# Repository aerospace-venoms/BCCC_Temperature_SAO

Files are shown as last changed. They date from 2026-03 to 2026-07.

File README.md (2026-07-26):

# BCCC SAO Temperature Badge

A Simple Add-On (SAO) badge for the DEF CON Beverage Chilling Contraption Contest (BCCC). Winners of the contest receive copies of this badge, at least for this year (2026) or until I run out.

The PCB is shaped like a red solo cup with overflowing beer. It reads ambient temperature using a DS18B20 sensor and displays the result in degrees Fahrenheit on three 7-segment LED displays.

## Hardware

- **MCU:** Raspberry Pi RP2350A (QFN-60)
- **Flash:** W25Q16 (2 MB)
- **Sensor:** DS18B20 1-Wire temperature sensor (GPIO 16); falls back to the RP2350's internal die sensor if not present
- **Display:** 3x common-anode 7-segment LED displays, multiplexed via a 74HC595 shift register
- **Interface:** USB-C (programming and serial debug output)
- **Extras:** 3-pin SWD debug header, user pushbuttons (RUN, QSPI_SS/BOOTSEL, and a brightness button on GPIO 19)

### Pin Assignments

| Signal | GPIO |
|---|---|
| 1-Wire (DS18B20) | 16 |
| Digit select 1 (leftmost) | 8 |
| Digit select 2 (middle) | 9 |
| Digit select 3 (rightmost) | 10 |
| 74HC595 SER (data) | 11 |
| 74HC595 SRCLK (shift clock) | 12 |
| 74HC595 RCLK (latch clock) | 13 |
| 74HC595 /OE (output enable) | 14 |
| 74HC595 /MR (master reset) | 15 |
| Brightness button (HW rev ≥ 1.3) | 19 |

## Firmware

The firmware uses the Raspberry Pi Pico SDK and is structured around both RP2350 cores:

- **Core 0** — reads temperature from the DS18B20 every ~1 second and updates the display buffer
- **Core 1** — continuously time-multiplexes the three 7-segment digits at ~333 Hz

If no DS18B20 is detected on the 1-Wire bus, the display shows `---` and the internal die temperature is logged to USB serial for reference.

On boards with hardware revision 1.3 or later, the brightness button (GPIO 19) cycles the display through four brightness levels.

### Prerequisites

- [Raspberry Pi Pico SDK](https://github.com/raspberrypi/pico-sdk) installed at `/usr/src/pico-sdk` (or update `PICO_SDK_PATH` in `CMakeLists.txt`)
- CMake 3.13+
- ARM GCC toolchain (`gcc-arm-none-eabi`)

On Debian/Ubuntu:

```sh
sudo apt install cmake gcc-arm-none-eabi libnewlib-arm-none-eabi build-essential
```

### Building

```sh
mkdir build && cd build
cmake ..
make -j$(nproc)
```

This produces `build/thermometer.uf2`.

### Flashing

Don't want to build from source? A prebuilt, versioned image is in [`firmware/`](firmware/) — handy if you need to recover a badge.

1. Hold the BOOTSEL button (QSPI_SS) while plugging in USB-C, or press and hold QSPI_SS then press RUN to reboot into bootloader mode.
2. The board will appear as a USB mass storage device named `RP2350`. (RP2040-based boards use `RPI-RP2`; the RP2350 reports `Board-ID: RP2350`.)
3. Copy the `.uf2` to the drive:

```sh
cp firmware/thermometer-v1.1.0.uf2 /media/$USER/RP2350/
# or, from a source build:
cp build/thermometer.uf2 /media/$USER/RP2350/
```

The board reboots automatically and starts running. At boot it prints its firmware version over USB serial:

```
BCCC Temperature SAO — firmware v1.1.0 (HW rev 13)
```

### Serial Debug Output

Connect a serial terminal at any baud rate (USB CDC ACM) to see temperature readings:

```sh
screen /dev/ttyACM0
# or
minicom -D /dev/ttyACM0
```

## Tooling

Helper scripts for building and for programming boards in quantity — see
[`tools/README.md`](tools/README.md) for full details.

| Script | Purpose |
|---|---|
| `scripts/bump-firmware.sh` | Rebuild and refresh the prebuilt UF2 so its filename always matches `FW_VERSION`. Pass a version (`1.1.0`) to bump first. |
| `tools/flash_and_test.py` | Watch for boards in BOOTSEL, flash each, then verify over USB serial that the firmware runs. Handles several boards at once. |
| `tools/soak_log.py` | Burn-in logger: timestamped output per board, recording disconnects and reboots. |
| `tools/soak_report.py` | Summarise a burn-in run (duration, drift, gaps, reboots) with a per-board verdict. |

Programming a batch:

```sh
tools/flash_and_test.py --log batch.csv
```

Leave it running and keep plugging boards in; Ctrl-C prints a summary. Boards
with no DS18B20 fitted report `PASS*` rather than failing, so this works before
the sensors are attached. Once they are, add `--require-sensor` to catch an
unpopulated or badly soldered sensor.

## Hardware Design

The KiCad project files are in `hardware/bccc_sao_rp2350a/`. The PCB artwork — a red solo cup with overflowing beer — was designed in [Inkscape](https://inkscape.org/), starting from an AI-generated image, then transferred into KiCad using the [SVG2Shenzhen](https://github.com/badgeek/svg2shenzhen) plugin.

Many thanks to the [KiCad](https://www.kicad.org/) project for excellent, free, open-source EDA software.

## License

[WTFPL v2](LICENSE) — do what the f*** you want with it.

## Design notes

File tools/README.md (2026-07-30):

# Production Test Tools

## `flash_and_test.py` — batch flash + verify station

Watches for RP2350 boards entering BOOTSEL mode, flashes each with the release
firmware, then reopens it as a serial device and confirms the firmware is
actually running. Handles several boards at once, so you can keep plugging in
cables without waiting for each to finish.

```sh
tools/flash_and_test.py                        # newest firmware/*.uf2, run until Ctrl-C
tools/flash_and_test.py --log run.csv          # append a per-board record
tools/flash_and_test.py --expect-version 1.1.0 # fail on a version mismatch
tools/flash_and_test.py --require-sensor       # only once DS18B20s are fitted
tools/flash_and_test.py --once                 # process what's plugged in, then exit
```

### How boards are kept straight in parallel

Every RP2350 reports a unique USB serial number (its chip ID), and it reports
the **same** value in BOOTSEL mode and when running the firmware. After
flashing a board, the tool finds the `/dev/ttyACM*` whose USB serial matches
that board, so results can never be attributed to the wrong cable. If a board
doesn't expose a serial string, it falls back to matching the physical USB port
path, which is also stable across the reboot.

Flashing targets one specific device via `picotool load -x --ser <serial>`, so
nothing depends on which volume auto-mounted where.

**picotool calls are serialised on purpose.** picotool opens candidate USB
devices to read their serial numbers, so two instances running at once make
each other's target look inaccessible — it reports "no accessible RP-series
device ... with serial number X" even though the board is plugged in and
perfectly healthy. Only the flash step holds that lock; it takes a second or
two, while the much slower per-board serial verification still runs fully in
parallel. Don't run a second picotool by hand while a batch is in progress.

### Verdicts

| Result | Meaning |
|---|---|
| `PASS` | Firmware runs, DS18B20 detected, ambient reading plausible (32–120 °F) |
| `PASS*` | Firmware runs, **no DS18B20 fitted** — fell back to internal die temp (40–190 °F) |
| `FAIL` | Flash failed, no serial port appeared, no output, too few readings, bad version, or an implausible temperature |

`PASS*` is a pass on purpose: this is expected before the sensors are attached.
Once they're fitted, add `--require-sensor` and a missing sensor becomes a
failure — that's how you catch an unpopulated or cold-jointed DS18B20.

**Read-back is retried.** The flash (picotool) and the verification (reading the
serial port back) are separate steps, and the *verification* can come up short
for reasons unrelated to a bad board: the port opened a beat late, USB was busy
with another board or the auto-mounted BOOTSEL volume, or the port briefly
resolved to the wrong device. So when a board flashes fine but the read-back is
short (too few readings / no output), the tool re-reads it (`--verify-retries`,
default 2) before calling it a FAIL. A genuinely dead board still yields nothing
across the retries; a healthy board that just lost the race passes. Real
firmware faults — version mismatch, implausible temperature, missing sensor when
required — are final and never retried. If you see many `only N readings` fails,
they are almost always flashed-and-fine boards, not scrap.

The boot banner (`firmware v1.1.0 (HW rev 13)`) prints once, ~1 s after boot.
The tool opens the port as fast as it can to catch it, but treats a missed
banner as non-fatal — the version is only enforced when it was actually seen.

## `soak_log.py` / `soak_report.py` — burn-in testing

For leaving boards running to prove they stay up over hours, not seconds.

```sh
tools/soak_log.py -o soak-logs      # follow every running board; Ctrl-C to stop
tools/soak_report.py -o soak-logs   # summarise the result
```

`soak_log.py` writes one timestamped log per board, named by chip serial. It
logs disconnects and reconnects as explicit events instead of ignoring them —
a board dropping off the USB bus or rebooting on its own is precisely what a
soak test is looking for. Run it detached (`setsid nohup ... &`) to survive a
closed terminal.

`soak_report.py` reports per board: run duration, reading count and rate,
temperature range and drift, gaps in the stream (`--gap`, default 10 s),
disconnect events, and whether the boot banner appeared more than once, which
means the board rebooted mid-run. Verdict is `HEALTHY` or `NEEDS REVIEW`;
exit status is non-zero if any board needs review.

Note that these hold the serial ports open, so stop the logger
(`pkill -f soak_log.py`) before flashing those boards again.

### Requirements

- `picotool` on `PATH` (v2.x). If it reports a permissions error, install its
  udev rules or run the tool with `sudo`.
- Python 3.9+ — standard library only, no pip installs.

### Notes

- Blank boards from the factory enumerate straight into BOOTSEL, so they're
  picked up automatically. An already-programmed board must be put into BOOTSEL
  by hand (hold BOOTSEL/QSPI_SS while plugging in) before it will be re-flashed.
- Re-plugging a board makes the tool treat it as a new unit, so retries just
  work.
- Results go to stdout live; `--log` writes CSV (timestamp, chip serial, port,
  status, version, sensor state, temperature) for traceability across a run.
  Each board's row is appended and flushed the moment it finishes, so an
  interrupted run — even a `kill` or a crash — keeps every board already tested.

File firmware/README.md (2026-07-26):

# Prebuilt Firmware

Ready-to-flash firmware images for the BCCC Temperature SAO. Use these if you
just want to (re)flash your badge without building from source.

| File | Version | Hardware |
|---|---|---|
| `thermometer-v1.1.0.uf2` | 1.1.0 | RP2350A, HW rev ≥ 1.3 |

## Flashing

1. Hold the **BOOTSEL** button (QSPI_SS) while plugging in USB-C — the board
   mounts as a USB drive named `RP2350`.
2. Copy the `.uf2` onto that drive:

   ```sh
   cp firmware/thermometer-v1.1.0.uf2 /media/$USER/RP2350/
   ```

3. The board reboots and runs automatically.

The running firmware reports its version over USB serial at boot:

```
BCCC Temperature SAO — firmware v1.1.0 (HW rev 13)
```

To rebuild this image from source, see the top-level [README](../README.md).
The version string lives in `CMakeLists.txt` (`FW_VERSION`).

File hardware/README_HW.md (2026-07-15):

This folder contains the information necessary to rebuild the hardware portion of the project. You can use the files in the 'ordering' folder to produce the PCB through e.g. JLCPCB, and you'll want to 3d print a diffuser_print.3mf to diffuse the LEDs so they shine through properly.

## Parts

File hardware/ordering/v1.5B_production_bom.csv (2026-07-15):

Designator | Footprint | Quantity | Value | LCSC Part #
C101, C102 | C_0402 | 2 | 15pF | C1548
C103, C105, C119, C301, C401 | C_0402 | 5 | 10uF | C15525
C104, C108, C111, C112, C113, C114, C115, C116, C117, C118 | C_0402 | 10 | 100nF | C1525
C106, C107 | C_0603 | 2 | 4.7uF | C19666
C109, C110 | C_0402 | 2 | 4.7uF | C23733
D101, D102 | SOT-23-3_L3.0-W1.7-P0.95-LS2.9-BR | 2 | PSM712-LF-T7 | C32677
D301, D401 | D_SMA | 2 | SS14 | C2480
D501, D502, D503, D504, D505, D506, D507, D508, D601, D602, D603, D604, D605, D606, D607, D608, D701, D702, D703, D704, D705, D706, D707, D708 | LED-SMD_L1.7-W1.1-R-RD_BULE | 24 | LED_Small | C965865
J101 | TYPE-C-SMD_HX-TYPE-C-16PIN | 1 | Connector, USB-TYPE-C-16P | C2927039
L101 | L_pol_2016 | 1 | 3.3u | C42411119
Q301, Q401 | Q_SOT-23 | 2 | SI2301CDS-T1-GE3 | C10487
Q501, Q601, Q701 | Q_SOT-23 | 3 | MDD2302 | C427390
R102, R103 | R_0402 | 2 | 5.1kΩ | C25905
R105 | R_0402 | 1 | 1kΩ | C11702
R106, R108 | R_0603 | 2 | 1kΩ | C21190
R107 | R_0402 | 1 | 33Ω | C25105
R109, R301, R401, R502, R602, R702 | R_0402 | 6 | 10kΩ | C25744
R110, R111 | R_0603 | 2 | 27Ω | C25190
R112 | R_0402 | 1 | 4.7kΩ | C25900
R201, R202, R203, R204, R205, R206, R207, R208 | R_0402 | 8 | 220Ω | C25091
R501, R601, R701 | R_0402 | 3 | 100Ω | C25076
S101, S102, S103 | SW_TS-1088-AR02016 | 3 | Tactile Button, 160gf | C720477
SAO_PORT | CONN-SMD_6P-P2.54_BH254VS | 1 | Simple_Addon_v2 | C492445
U101 | SOIC-8_5.3x5.3mm_P1.27mm | 1 | W25Q16JVSS | C131025
U102 | SOT-223-3_L6.5-W3.4-P2.30-LS7.0-BR | 1 | AMS1117 | C6186
U103 | RP2350-QFN-60-1EP_7x7_P0.4mm_EP3.4x3.4mm_ThermalVias | 1 | RP2350_60QFN | C42411118
U201 | SOIC-16_L9.9-W3.9-P1.27-LS6.0-BL | 1 | 74HC595D | C5947
Y101 | Crystal_SMD_3225-4Pin_3.2x2.5mm | 1 | ABM8-272-T3

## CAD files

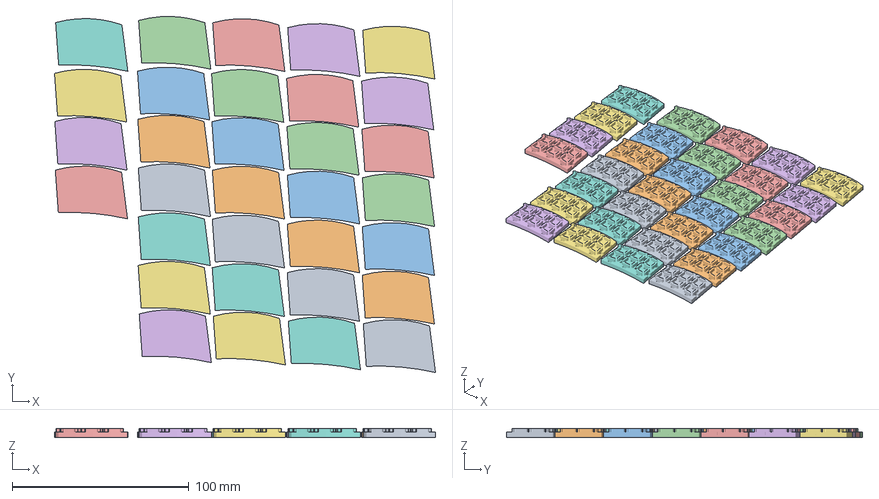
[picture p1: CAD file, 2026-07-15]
hardware/diffuser_print.3mf
215.3 x 201.2 x 5.10 mm
bccc_sao_diffuser_notext x 5

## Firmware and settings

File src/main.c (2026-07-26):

// Step 2: Temperature sensing with DS18B20 (or RP2350 internal fallback)
//
// Core 0: reads temperature every ~1 s and updates the display buffer.
// Core 1: time-multiplexes the 3-digit display continuously at ~333 Hz.
//
// Display behaviour:
//   DS18B20 present  → temperature in °F on the 7-segment display
//   DS18B20 absent   → "---" on the display; internal die temp logged to serial

#include "pico/stdlib.h"
#include "pico/multicore.h"
#include "display.h"
#include "temp.h"
#include "ds18b20.h"    // for PIN_OW
#include <stdio.h>

#ifndef FW_VERSION
#define FW_VERSION "0.0.0-dev"   // fallback if not set by the build
#endif

#define DIGIT_ON_US 333     // ~333 µs per digit → ~1 kHz full refresh

// ---------------------------------------------------------------------------
// Brightness control (HW_REV >= 13: button on GPIO 19)
// ---------------------------------------------------------------------------
#if HW_REV >= 13

#define PIN_BRIGHT_BTN  19
// Brightness levels as percentage of DIGIT_ON_US.
// Easy to tweak: just edit this array.
static const uint8_t BRIGHT_PCT[] = { 100, 66, 33, 15 };
#define NUM_BRIGHT_LEVELS (sizeof(BRIGHT_PCT) / sizeof(BRIGHT_PCT[0]))

static volatile int s_bright_idx = 0;

// 200 ms debounce. Deliberately long for a mechanical tactile switch: it
// swallows contact bounce and also stops a single firm press from advancing
// the brightness level more than once.
#define DEBOUNCE_US 200000

static void brightness_isr(uint gpio, uint32_t events) {
    (void)events;
    if (gpio != PIN_BRIGHT_BTN) return;

    static uint64_t last_us = 0;
    uint64_t now = time_us_64();
    if (now - last_us < DEBOUNCE_US) return;
    last_us = now;

    s_bright_idx = (s_bright_idx + 1) % NUM_BRIGHT_LEVELS;
}

static void brightness_init(void) {
    gpio_init(PIN_BRIGHT_BTN);
    gpio_set_dir(PIN_BRIGHT_BTN, GPIO_IN);
    gpio_pull_up(PIN_BRIGHT_BTN);
    gpio_set_irq_enabled_with_callback(PIN_BRIGHT_BTN,
        GPIO_IRQ_EDGE_FALL, true, brightness_isr);
}

#endif // HW_REV >= 13

// ---------------------------------------------------------------------------
// Core 1: display multiplexer
// ---------------------------------------------------------------------------
static void core1_display_loop(void) {
    int digit = 0;
    while (true) {
#if HW_REV >= 13
        int on_us = DIGIT_ON_US * BRIGHT_PCT[s_bright_idx] / 100;
        display_refresh(digit);
        sleep_us(on_us);
        // Blank remainder of time slot for dimming
        for (int i = 0; i < NUM_DIGITS; i++)
            gpio_put(8 + i, 0);    // PIN_DIG1..3 = GPIO 8..10
        sleep_us(DIGIT_ON_US - on_us);
#else
        display_refresh(digit);
        sleep_us(DIGIT_ON_US);
#endif
        if (++digit >= NUM_DIGITS) digit = 0;
    }
}

// ---------------------------------------------------------------------------
// Core 0: application
// ---------------------------------------------------------------------------
int main(void) {
    stdio_init_all();
    sleep_ms(1000);     // give USB CDC time to enumerate

    printf("BCCC Temperature SAO — firmware v%s (HW rev %d)\n", FW_VERSION, HW_REV);

    display_init();
    // Segment self-test: light every segment and all three decimal points
    // ("8.8.8.") so the whole display can be eyeballed during flashing/QC.
    display_set_raw(SEG_ALL_ON | SEG_DP, SEG_ALL_ON | SEG_DP, SEG_ALL_ON | SEG_DP);

    multicore_launch_core1(core1_display_loop);

    // Boot splash: "8.8.8." (self-test) → "DEF" → "C0n" → "LoL"
    sleep_ms(1000);
    display_set_raw(SEG_CHR_D, SEG_CHR_E, SEG_CHR_F);
    sleep_ms(1000);
    display_set_raw(SEG_CHR_C, SEG_DIGITS[0], SEG_CHR_n);
    sleep_ms(1000);
    display_set_raw(SEG_CHR_L, SEG_CHR_o, SEG_CHR_L);
    sleep_ms(1000);

#if HW_REV >= 13
    brightness_init();
#endif

    temp_init();

    if (temp_has_ds18b20()) {
        printf("Sensor: DS18B20 on GPIO %d\n", PIN_OW);
    } else {
        printf("Sensor: DS18B20 not found on GPIO %d\n", PIN_OW);
        printf("        Displaying --- ; internal die temp logged here.\n");
    }

    while (true) {
        if (temp_has_ds18b20()) {
            float f = temp_read_f();
            display_set_temp_f(f);
            printf("DS18B20:  %.1f F\n", f);
        } else {
            // No external sensor — keep "---" on the display.
            // The internal sensor is not an ambient thermometer, so we
            // log it to serial for information only.
            display_set_raw(SEG_DASH, SEG_DASH, SEG_DASH);
            printf("Internal: %.1f F  (die temp, not ambient)\n",
                   temp_read_internal_f());
        }
        sleep_ms(100);
    }
}

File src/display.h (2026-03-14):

#pragma once
#include <stdint.h>
#include <stdbool.h>

// ---------------------------------------------------------------------------
// 74HC595 shift register pin assignments
// ---------------------------------------------------------------------------
#define PIN_SR_DATA     11  // SER  – serial data in
#define PIN_SR_SRCLK    12  // SRCLK – shift register clock
#define PIN_SR_RCLK     13  // RCLK  – storage register (latch) clock
#define PIN_SR_OE       14  // /OE   – output enable (active low, pull LOW to enable)
#define PIN_SR_MR       15  // /MR   – master reset  (active low, pull HIGH to run)

// ---------------------------------------------------------------------------
// Digit select pins (active HIGH via N-MOS; HIGH = digit anode energised)
// ---------------------------------------------------------------------------
#define PIN_DIG1        8   // leftmost digit
#define PIN_DIG2        9   // middle digit
#define PIN_DIG3        10  // rightmost digit
#define NUM_DIGITS      3

// ---------------------------------------------------------------------------
// Segment byte encoding
// Bit position → 74HC595 output → display segment
//   bit 0 → QA → segment a (top)
//   bit 1 → QB → segment b (top-right)
//   bit 2 → QC → segment c (bottom-right)
//   bit 3 → QD → segment d (bottom)
//   bit 4 → QE → segment e (bottom-left)
//   bit 5 → QF → segment f (top-left)
//   bit 6 → QG → segment g (middle)
//   bit 7 → QH → decimal point
//
// Sent MSB-first into SER; after 8 SRCLK pulses the last bit ends up at QA.
// ---------------------------------------------------------------------------
#define SEG_DP  (1 << 7)

// Segment patterns for '0'–'9' (no decimal point)
extern const uint8_t SEG_DIGITS[10];

// Segment patterns for a few extra glyphs
#define SEG_DASH    0x40    // segment g only  ( – )
#define SEG_ALL_ON  0x7F    // all segments, no DP
#define SEG_BLANK   0x00    // all off

// Letter glyphs
#define SEG_CHR_C   0x39    // C: a d e f
#define SEG_CHR_D   0x5E    // D: b c d e g  (lowercase d shape — no true uppercase D)
#define SEG_CHR_E   0x79    // E: a d e f g
#define SEG_CHR_F   0x71    // F: a e f g
#define SEG_CHR_L   0x38    // L: d e f
#define SEG_CHR_n   0x54    // n: c e g  (no true uppercase N)
#define SEG_CHR_o   0x3F    // o: a b c d e f  (same as '0')

// ---------------------------------------------------------------------------
// Public API
// ---------------------------------------------------------------------------

// Initialise all display GPIOs, reset/enable the shift register.
void display_init(void);

// Write one byte to the shift register and latch it.
void display_sr_write(uint8_t segments);

// Set the raw segment byte for each digit (index 0 = leftmost).
// This does NOT change the display immediately – call display_refresh() in
// your multiplex loop.
void display_set_raw(uint8_t d0, uint8_t d1, uint8_t d2);

// Show an integer 0–999. Values outside range show "---".
void display_set_number(int value);

// Show a temperature in degrees Fahrenheit.
//   < 0 °F        →  "-XX"  (no decimal)
//   0–99.9 °F     →  "XX.X" (one decimal place, DP on middle digit)
//   100–999 °F    →  "NNN"  (integer, no decimal)
//   out of range  →  "---"
void display_set_temp_f(float temp_f);

// Show one digit on one digit position (0–2), all others blank.
// Useful for testing individual positions.
void display_set_digit(int pos, uint8_t segments);

// Drive one multiplex frame: turn off all digits, shift in segments for
// `digit` (0–2), turn that digit on.  Call this in a tight loop at >1 kHz
// per digit (i.e. cycle through all three digits faster than ~300 Hz total).
void display_refresh(int digit);

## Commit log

2026-03-14 Initial project setup: display driver and 7-segment bringup
    Adds 74HC595 shift-register driver, 3-digit time-multiplexed 7-segment
    display library, and a diagnostic test sequence that sweeps all segments
    and counts 000-999. Targets RP2350A (pico2 board) with 16 MB W25Q128 flash.
2026-03-14 Add temperature sensing: DS18B20 with RP2350 internal ADC fallback
    Implements a 1-Wire software driver for the DS18B20 on GPIO 16 using
    the RP2350's internal pull-up. If the sensor is absent at startup the
    firmware falls back to the on-chip ADC temperature sensor (channel 4)
    and prints a notice over USB serial. If DS18B20 contact is lost at
    runtime it also falls back automatically.
    Display multiplexing is moved to core 1 so the 750 ms DS18B20 conversion
    on core 0 doesn't cause the display to go dark. Temperature is shown in
    °F: "XX.X" below 100 °F (decimal on middle digit), "NNN" at 100 °F and
    above. Readings and active sensor are reported over USB CDC serial.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
    [display.c, display.h, ds18b20.c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]
2026-03-14 Fix DS18B20 returning out-of-range readings by validating CRC
    Add CRC-8/Maxim validation of the 9-byte scratchpad (crc8 over all 9
    bytes including the CRC byte must equal 0). Also add a -55..125 °C
    range check matching the DS18B20 spec. Either failure returns false,
    which causes temp.c to fall back to the RP2350 internal ADC sensor
    instead of displaying "---" from the garbage temperature value.
    [ds18b20.c]
2026-03-14 Fix display logic and 1-Wire timing
    Two fixes:
    - Display "---" when DS18B20 is absent; internal die temperature is
    logged to USB serial only (it is not an ambient reading so displaying
    it on the thermometer would be misleading).
    - Widen all 1-Wire timing margins to account for sleep_us() call
    overhead (~1-2 µs): reset pulse 500 µs, slot 70 µs, read sample
    pushed to 13 µs. This prevents marginal read-slot timing that caused
    CRC failures on the DS18B20 scratchpad read.
    Also adds temp_read_internal_f() so main.c can log die temperature
    without coupling it to the DS18B20 read path.
    [ds18b20.c, main.c, temp.c]
2026-03-14 added 3d printable file for LED diffuser
    [diffuser_print.3mf]
2026-03-14 Switch license from MIT to WTFPL v2
2026-03-14 starting to add hw information
    [diffuser_print.3mf]
2026-03-14 added hardware .gitignore
    [diffuser_print.3mf]
2026-03-14 adding initial hw source
    [diffuser_print.3mf]
2026-03-14 added kicad files for rebuildability
    [3-digit-multiplexer.kicad_sch, 8seg_digit.kicad_sch, bccc_sao_rp2350a.kicad_sch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]
2026-03-14 debugged and fixed a display digit flicker
    [display.c, display.h, main.c]
2026-03-15 added build option to not time-multiplex digits, thus allowing me to measure voltage drop across LED
2026-03-15 hardware edits, changed LED resistor 470->220 ohm, more 'documentation' on board
    [3-digit-multiplexer.kicad_sch, 8seg_digit.kicad_sch, bccc_sao_rp2350a.kicad_sch]
2026-03-15 changed to a more economical spi flash chip, cut zsh.5/board
    [bccc_sao_rp2350a.kicad_sch]
2026-07-15 firmware+docs: finalize for public release
    - Set flash size to 2 MB (W25Q16) and drop the MEASURE_LED_VF debug flag
    - Add HW_REV-gated brightness button (GPIO 19) and 4-level dimming
    - Correct README flash chip (W25Q128->W25Q16), document brightness button,
    and point hardware README at the ordering/ folder for fabrication
    [main.c]
2026-07-15 hardware: v1.5B design + canonical fabrication files
    - Update KiCad PCB/schematic/project to the v1.5B production design that
    matches the boards being manufactured for DEF CON 34
    - Add hardware/ordering/ with the v1.5B gerbers, BOM, and pick-and-place
    files so others can fabricate the board directly
    - Update diffuser print model
    [bccc_sao_rp2350a.kicad_pcb, bccc_sao_rp2350a.kicad_sch, diffuser_print.3mf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]
2026-07-15 firmware: add version stamp and prebuilt UF2 for recovery
    - Add FW_VERSION (1.0.0) in CMakeLists, embedded in the binary and printed
    over USB serial at boot for easy identification
    - Commit a prebuilt firmware/thermometer-v1.0.0.uf2 so badge holders can
    reflash/recover without a toolchain, with a firmware/ README
    - Add a .gitignore exception so release UF2s are tracked; document the
    prebuilt-flash path in the main README
2026-07-22 firmware: lengthen brightness debounce to 200 ms; fix BOOTSEL drive name
    - Raise DEBOUNCE_US from 20 ms to 200 ms so a single firm press advances the
    brightness level exactly once on the mechanical tactile switch
    - Correct the bootloader drive name in the docs: RP2350 boards enumerate as
    RP2350, not RPI-RP2 (verified on hardware, Board-ID: RP2350)
    - Bump FW_VERSION to 1.0.1 and regenerate the prebuilt UF2
    Verified on a prototype: flashes cleanly and reports
    "BCCC Temperature SAO — firmware v1.0.1 (HW rev 13)" over USB serial.
    [main.c]
2026-07-23 tools: add parallel flash + test station for production runs
    flash_and_test.py watches for RP2350 boards in BOOTSEL, flashes each with
    picotool, then reopens it as a serial device and verifies the firmware runs.
    Several boards are handled concurrently, one worker thread each.
    Boards are tracked by chip serial number, which the bootloader and the running
    firmware report identically (verified on hardware). That is what makes parallel
    operation safe: a board's post-flash serial port is matched back to the exact
    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
2026-07-23 tools: serialise picotool calls, fix misleading permission hint
    Concurrent picotool invocations make each other fail: picotool opens candidate
    USB devices to read their serial numbers, so two instances racing report "no
    accessible RP-series device ... with serial number X" for boards that are
    plugged in and healthy. Verified directly - each --ser call succeeds alone and
    both fail when run at the same time.
    Flashing now holds a lock, so picotool runs one at a time. Flashing is quick;
    the slow per-board serial verification still runs fully in parallel. Also retry
    a failed load once, to ride out a board caught mid-re-enumeration.
    The udev/sudo hint now only appears for genuine permission erro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
    [flash_and_test.py]
2026-07-23 tools: add burn-in soak logger and report
    soak_log.py follows every running board and writes a timestamped log per chip
    serial, recording disconnects and reconnects as explicit events - a board
    dropping off the bus or rebooting on its own is the failure a soak test is
    meant to catch, so it must not be silently swallowed.
    soak_report.py summarises a run: duration, reading count and rate, temperature
    range and drift, gaps in the stream, disconnect events, and repeat boot banners
    indicating a mid-run reboot. Exits non-zero if any board needs review.
    Generated logs are gitignored.
    [soak_log.py, soak_report.py]
2026-07-23 docs: document the build and production tooling in the README
    The README described building and flashing a single board but never mentioned
    scripts/ or tools/, so the batch flash/test and burn-in tooling was
    undiscoverable from the front page. Adds a Tooling section pointing at
    tools/README.md, and gitignores the local session handoff notes.
2026-07-26 firmware: add 8.8.8. segment self-test to boot splash (v1.1.0)
    Light every segment and all three decimal points ("8.8.8.") as the first boot
    frame, before DEF/C0n/LoL, so an operator can verify the whole display during
    flashing/QC.
    The splash is now 4 frames (~4 s) before the first temperature reading, so the
    flasher's serial capture window is widened 6 s -> 10 s. At 6 s the longer splash
    left too little time to collect the 3 readings a PASS requires, which would fail
    good boards (one such false FAIL was already seen at the old 3-frame margin).
    Bumped FW_VERSION to 1.1.0, regenerated the prebuilt UF2, and updated version
    references in the docs.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
    [flash_and_test.py, main.c]
2026-07-26 tools: make flash/test CSV log durable, gitignore batch logs
    Each board's result is now appended to the --log CSV and fsync'd the moment it
    finishes, instead of only being written on a clean Ctrl-C exit. An interrupted
    run - a kill (SIGTERM), a crash, a power loss - now keeps every board already
    tested. Previously such an exit discarded the whole run's record.
    Also gitignore batch-*.csv production logs so they aren't committed by accident.
    Verified on hardware: board flashed v1.1.0, PASS, row written incrementally.
    [flash_and_test.py]
2026-07-30 tools: retry serial read-back so flashed-but-flaky boards aren't failed
    Production data showed ~47% of boards logging FAIL, almost all "only N
    readings; main loop may be stalled" - yet the flash (picotool) had succeeded on
    every one, and none ever passed on a later attempt because the operator just
    re-plugged and eyeballed the display. These were false failures: the board was
    flashed and running, but the serial read-back came up short (port opened late,
    USB busy with another board or the auto-mounted BOOTSEL volume, or the port
    resolved to the wrong device for a moment).
    The read-back now retries (--verify-retries, default 2), re-resolving the port
    each time. A genuinely dead board still yi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
    [flash_and_test.py]
